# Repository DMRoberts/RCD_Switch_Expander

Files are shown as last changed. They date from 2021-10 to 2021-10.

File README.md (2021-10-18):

# RCD Switch Expander
PCB and Panel files for a Eurorack switch expander. Designed for the 4MS Rotating Clock Divider (RCD), however it should be useable with any Eurorack module where a SPDT switch can replace a three-pin jumper.

### PCB

PCB is designed using KiCad.

### Panel

The panel was produced via Front Panel Express ([https://www.frontpanelexpress.com/](https://www.frontpanelexpress.com/)). The included Front Design file (FPD) can be used to order the same panel. The panel text was created in Affinity Designer, and imported into Front Design as a graphic object. To change the text, you can either:

A. Replace the graphic object with text engravings:

1. Delete the graphic layer in Front Design.
2. Insert Front Design text engravings.

B. Update the graphic object:

1. Open the included .AI file in a program that can edit Adobe Illustrator files.
2. Edit the text.
3. Hide all non-text layers (they are only there as a reference)
4. Export to PDF
5. Replace the PDF in the 'File' field of the graphic object with your updated object.

### Bill of Materials

| Description | Quantity | Manufacturer Part #  | Notes |
|---|---|---|---|
| Sub Miniature SPDT On-On Switches | 6 | 108-0042-EVX | Switch with same specs available from Thonk (DW1): https://www.thonk.co.uk/shop/sub-mini-toggle-switches/ |
| 1 Row x 3 Pin Male Pin Header (2.54 pitch) | 6 | 68001-403HLF | Optional, can also solder wires directly to board, or break apart a longer row of 2.54 mm headers |
| 2.54 mm Female to Female Jumper Cables | 12 | Various - Check Ebay | Optinal, if used need 12 for RCD (2 for each switch) |

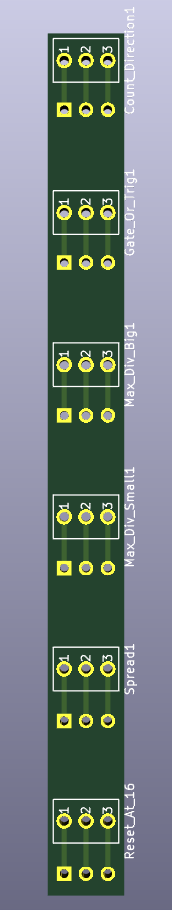
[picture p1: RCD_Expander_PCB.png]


<br>

<br>


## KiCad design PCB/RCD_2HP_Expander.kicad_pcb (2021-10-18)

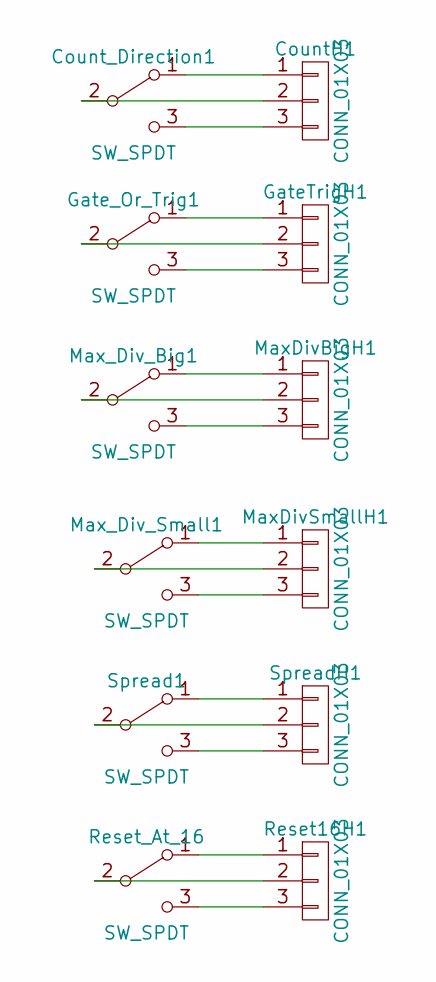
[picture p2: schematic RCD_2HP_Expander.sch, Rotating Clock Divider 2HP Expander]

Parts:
CountH1: CONN_01X03; Pin_Header_Straight_1x03_Pitch2.54mm
Count_Direction1: SW_SPDT; DW1-SPDT-ON-ON
GateTrigH1: CONN_01X03; Pin_Header_Straight_1x03_Pitch2.54mm
Gate_Or_Trig1: SW_SPDT; DW1-SPDT-ON-ON
MaxDivBigH1: CONN_01X03; Pin_Header_Straight_1x03_Pitch2.54mm
MaxDivSmallH1: CONN_01X03; Pin_Header_Straight_1x03_Pitch2.54mm
Max_Div_Big1: SW_SPDT; DW1-SPDT-ON-ON
Max_Div_Small1: SW_SPDT; DW1-SPDT-ON-ON
Reset16H1: CONN_01X03; Pin_Header_Straight_1x03_Pitch2.54mm
Reset_At_16: SW_SPDT; DW1-SPDT-ON-ON
Spread1: SW_SPDT; DW1-SPDT-ON-ON
SpreadH1: CONN_01X03; Pin_Header_Straight_1x03_Pitch2.54mm

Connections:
unnamed: CountH1.1, Count_Direction1.1 (A)
unnamed: CountH1.2, Count_Direction1.2 (B)
unnamed: CountH1.3, Count_Direction1.3 (C)
unnamed: GateTrigH1.1, Gate_Or_Trig1.1 (A)
unnamed: GateTrigH1.2, Gate_Or_Trig1.2 (B)
unnamed: GateTrigH1.3, Gate_Or_Trig1.3 (C)
unnamed: MaxDivBigH1.1, Max_Div_Big1.1 (A)
unnamed: MaxDivBigH1.2, Max_Div_Big1.2 (B)
unnamed: MaxDivBigH1.3, Max_Div_Big1.3 (C)
unnamed: MaxDivSmallH1.1, Max_Div_Small1.1 (A)
unnamed: MaxDivSmallH1.2, Max_Div_Small1.2 (B)
unnamed: MaxDivSmallH1.3, Max_Div_Small1.3 (C)
unnamed: Reset16H1.1, Reset_At_16.1 (A)
unnamed: Reset16H1.2, Reset_At_16.2 (B)
unnamed: Reset16H1.3, Reset_At_16.3 (C)
unnamed: Spread1.1 (A), SpreadH1.1
unnamed: Spread1.2 (B), SpreadH1.2
unnamed: Spread1.3 (C), SpreadH1.3

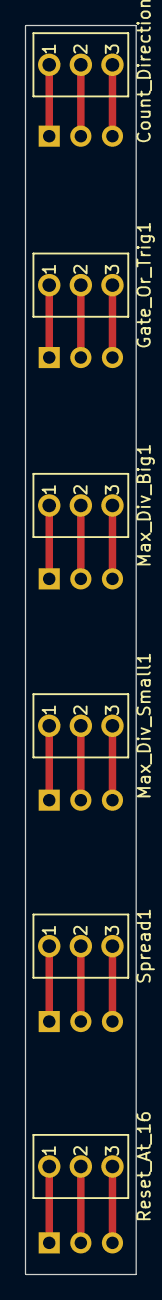
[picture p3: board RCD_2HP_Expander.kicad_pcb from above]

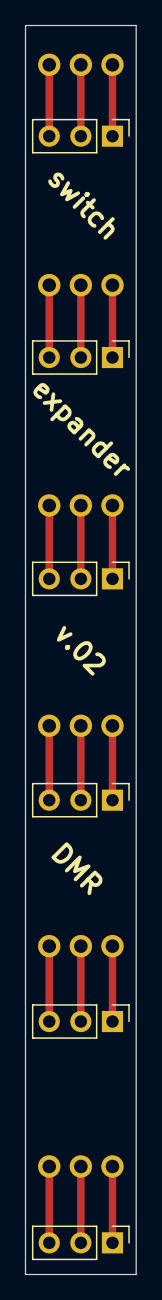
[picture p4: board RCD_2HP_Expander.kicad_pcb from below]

Board: 2 copper layers, 8.9 x 100.3 mm, 12 parts (6 on the bottom side), 18 nets.
